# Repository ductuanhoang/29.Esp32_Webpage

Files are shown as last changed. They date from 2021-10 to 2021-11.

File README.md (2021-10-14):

# Smart hammer

This project will read data as : accelerometer and buttons and push add to AWS
* build in ESP32-IDF

#How to config wifi connect to your AP  
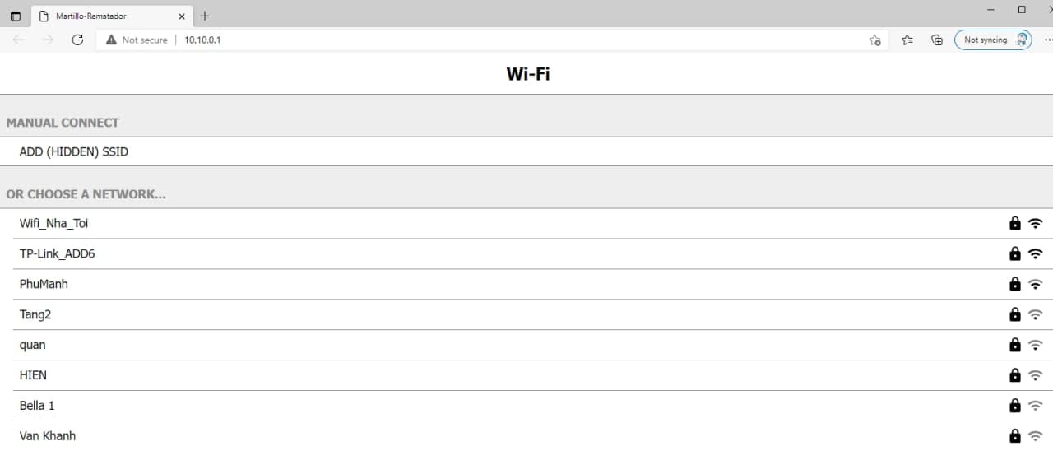
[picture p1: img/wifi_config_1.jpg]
  
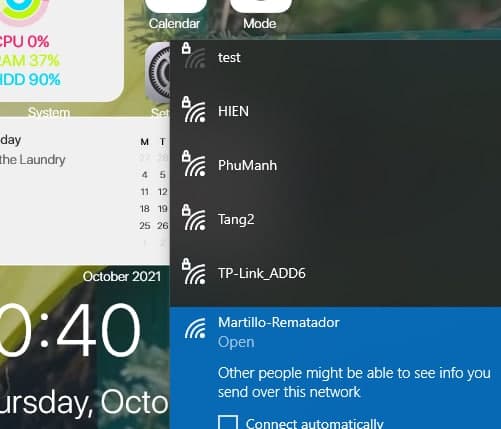
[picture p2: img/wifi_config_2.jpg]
  
#How to detect hit using Z axis  
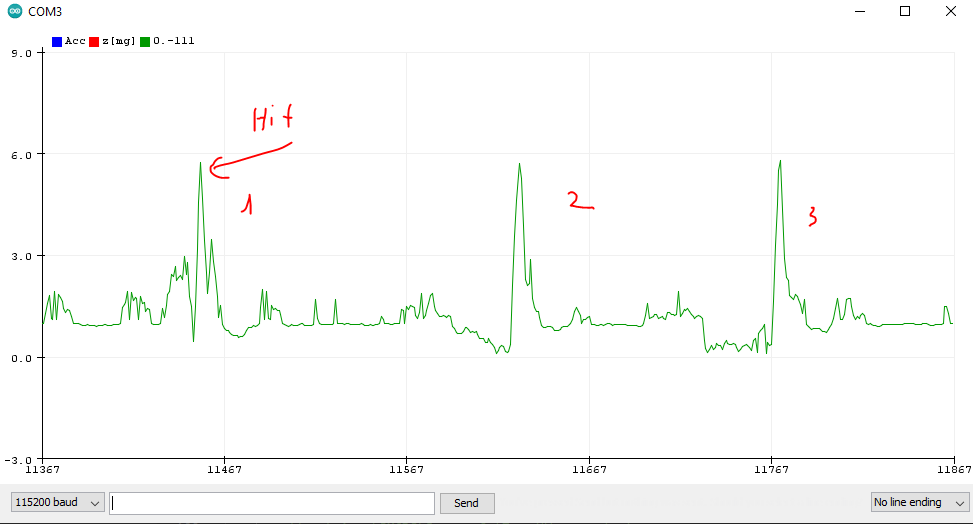
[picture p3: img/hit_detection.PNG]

#How to download the code to the esp32  
user can use "flash_download_tool" for download bin file to the esp32  
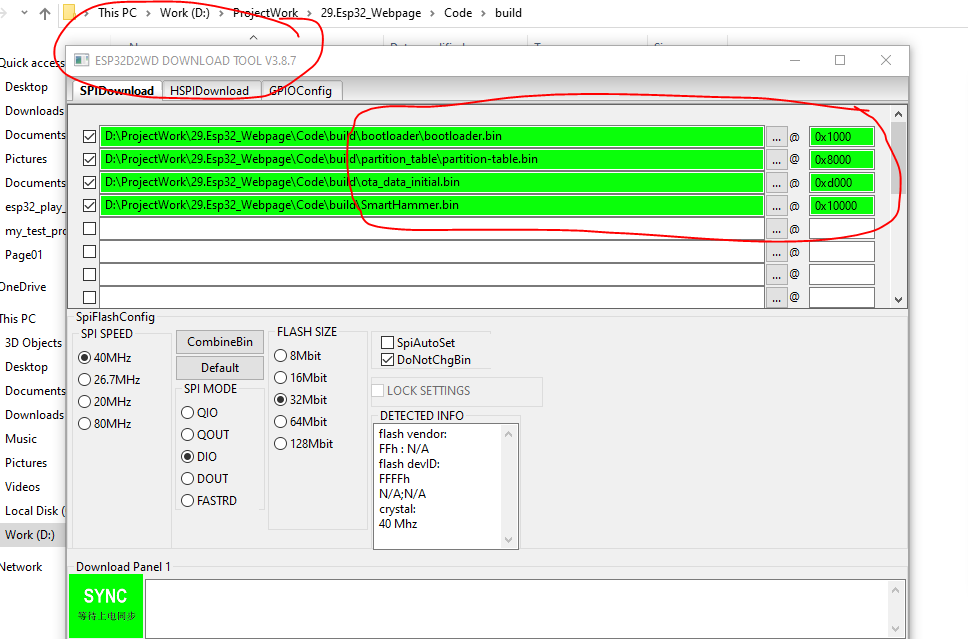
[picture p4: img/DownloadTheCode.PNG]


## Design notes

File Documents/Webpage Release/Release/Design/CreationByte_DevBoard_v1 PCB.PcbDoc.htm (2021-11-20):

Reporting Options

# File in Newer Format

Date | : | 10/28/2021
Time | : | 8:25:45 AM
Filename | : | D:\ProjectWork\29.Esp32_Webpage\Documents\Webpage Release\Release\Design\CreationByte_DevBoard_v1 PCB.PcbDoc

Version | Warning
Release 20.0 | CAUTION - Support of propagation delay for primitives

This file was generated by a later version of the software

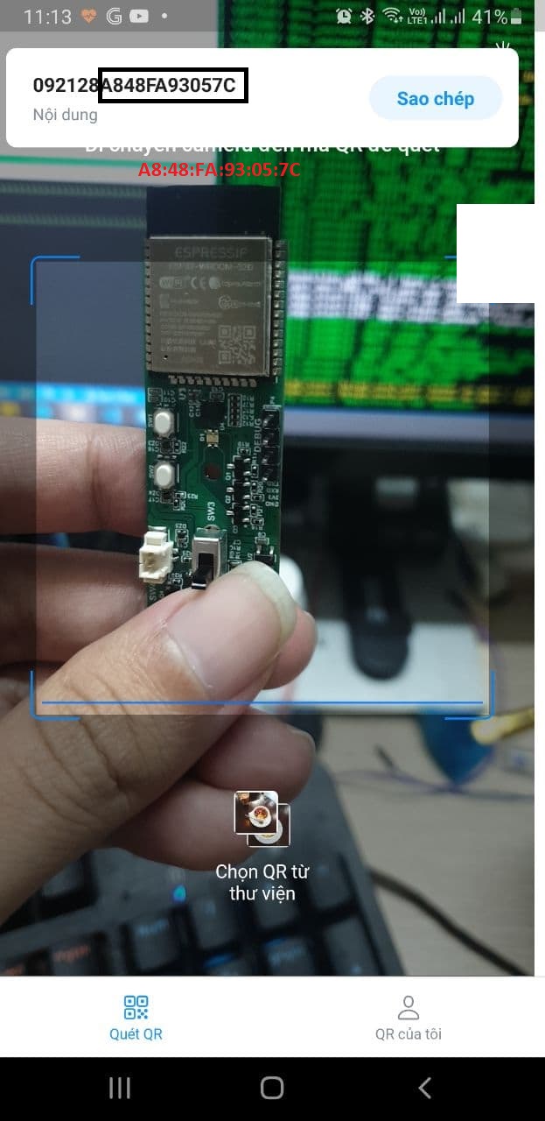
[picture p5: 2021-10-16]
img/QR_MAC_Adress.jpg

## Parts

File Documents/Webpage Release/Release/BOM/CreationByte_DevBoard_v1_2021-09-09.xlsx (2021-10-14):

Comment | Manufacturer 1 | Manufacturer Part Number 1 | Description | Designator | Quantity | SMT Quantity | Extended Price
1N4148WS | ON Semiconductor / Fairchild | 1N4148WS | DIODE GEN PURP 75V 150MA SOD323F | D2, D3 | 2 | 10 | 1.92
19-237D/BHR6GHC-C01/2T | Everlight | 19-237D/BHR6GHC-C01/2T | LED RGB CLEAR 4SMD | D1 | 1 | 5 | 1.75
BC817-25-7-F | Diodes | BC817-25-7-F | TRANS NPN 45V 500MA SOT23-3 | Q1, Q2, Q3, Q4 | 4 | 20 | 3.6
BQ24074RGTR | Texas Instruments | BQ24074RGTR | IC BATT CHG LI-ION 1CELL 16QFN | U1 | 1 | 5 | 11.5
10uF | Samsung | CL05A106MP8NUB8 | CAP CER 10UF 10V X5R 0402 | C1, C2, C3, C4, C5, C6, C8, C9, C10, C12, C15 | 11 | 55 | 9.92
0.01uF | Samsung | CL05B103KA5NNNC | CAP CER 10000PF 25V X7R 0402 | C7 | 1 | 5 | 0.5
ESP32-WROOM-32D (16MB) | Espressif Systems | ESP32-WROOM-32D (16MB) | RX TXRX MOD WIFI TRACE ANT SMD | U3 | 1 | 5 | 23.25
0.1uF | Murata | GRM155R71H104KE14D | CAP CER 0.1UF 50V X7R 0402 | C11, C13, C14, C16, C17, C18, C19 | 7 | 35 | 1.19
LCM0834A1195F | LEADER | LCM0834A1195F | Coin Type Vibration Motor | P6 | 1 | 5 | 1.64
LP502060 | Shenzhen Everwin Tech | LP502060 | LITHIUM POLYMER BATTERY 510mAh 60mm x 20mm x 5mm | P2 | 1 | 10 | 20
LSM6DSL | STMicroelectronics | LSM6DSLTR | IMU ACCEL/GYRO I2C/SPI 14LGA | U4 | 1 | 5 | 26.35
OS102011MS2QN1 | ITT C&K | OS102011MS2QN1 | Slide | SW3 | 1 | 5 | 2.55
PTS636 SP50 SMTR LFS | ITT C&K | PTS636SP50SMTRLFS | PTS636 Series SPST-NO Off-Mom 320 gf Top Actuated Gull Wing SMT Tactile Switch | SW4 | 1 | 5 | 0.6
PTS810SJK250SMTRLFS | ITT C&K | PTS810SJK250SMTRLFS | SWITCH TACTILE SPST-NO 0.05A 16V | SW1, SW2 | 2 | 10 | 3.13
1k | Yageo | RC0402FR-071KL | RES SMD 1K OHM 1% 1/16W 0402 | R1, R2, R11, R14, R16, R17, R18 | 7 | 35 | 0.56
10k | Yageo | RC0402FR-0710KL | RES SMD 10K OHM 1% 1/16W 0402 | R3, R4, R5, R6, R7, R8, R12, R13, R15, R22, R23, R25 | 12 | 60 | 0.96
33R | Yageo | RC0402FR-0733RL | RES SMD 33 OHM 1% 1/16W 0402 | R26 | 1 | 5 | 0.5
100R | Yageo | RC0402FR-07100RL | RES SMD 100 OHM 1% 1/16W 0402 | R19, R20, R21 | 3 | 15 | 0.24
100k | Yageo | RC0402JR-07100KL | RES SMD 100K OHM 1% 1/16W 0402 | R9, R10, R24 | 3 | 15 | 0.2
TPD1E10B06DPYR | Texas Instruments | TPD1E10B06DPYR | TVS DIODE 5.5V 14V 2X1SON | DZ1, DZ2, DZ3, DZ4, DZ5 | 5 | 25 | 7.43
TYPE-C-31-M-17 | Korean Hroparts Elec | TYPE-C-31-M-17 | USB - Type C Female 6 USB Connectors RoHS | USB1 | 1 | 5 | 6.4
XC6220B331MR-G | Torex | XC6220B331MR-G | IC REG LINEAR 3.3V 1A SOT25 | U2 | 1 | 5 | 4.8
PCB |  |  | PCB 2 LAYERS HASL WITH LEAD 63x20x1mm |  | 1 | 5 | 60
SMT |  |  | SMT FOR BOARD |  | 1 | 5 | 80
SMT Stencil and Setup Cost |  |  |  |  |  |  | 50
Shipping cost for total BoM |  |  |  |  |  |  | 30
Shipping cost for battery |  |  |  |  |  |  | 45
Tax fee (USD) |  |  |  |  |  |  | 59.0985
Total Price (USD) |  |  |  |  |  |  | 453.0885
Please send the payment to my PAYPAL then I can work with suppliers and factories to build prototype
My paypal accout: | manhnv.etk56@gmail.com

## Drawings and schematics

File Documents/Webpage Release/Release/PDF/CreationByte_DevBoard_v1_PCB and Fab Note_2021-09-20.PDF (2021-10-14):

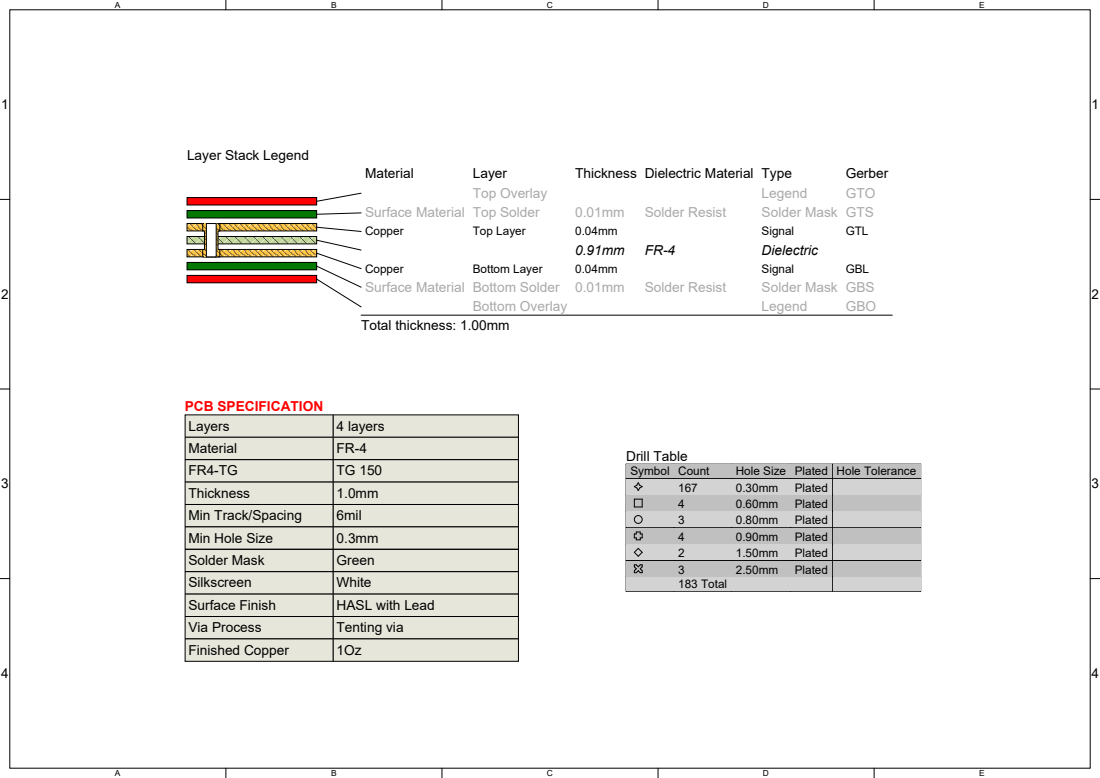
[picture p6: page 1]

Layers | 4 layers
Material | FR-4
FR4-TG | TG 150
Thickness | 1.0mm
Min Track/Spacing | 6mil

Symbol | Count | Hole Size | Plated | Hole Tolerance

167 | 0.30mm | Plated
4 | 0.60mm | Plated
3 | 0.80mm | Plated

2 | 1.50mm | Plated
3 | 2.50mm | Plated
183 Total

Solder Mask | Green
Silkscreen | White
Surface Finish | HASL with Lead
Via Process | Tenting via
Finished Copper | 1Oz

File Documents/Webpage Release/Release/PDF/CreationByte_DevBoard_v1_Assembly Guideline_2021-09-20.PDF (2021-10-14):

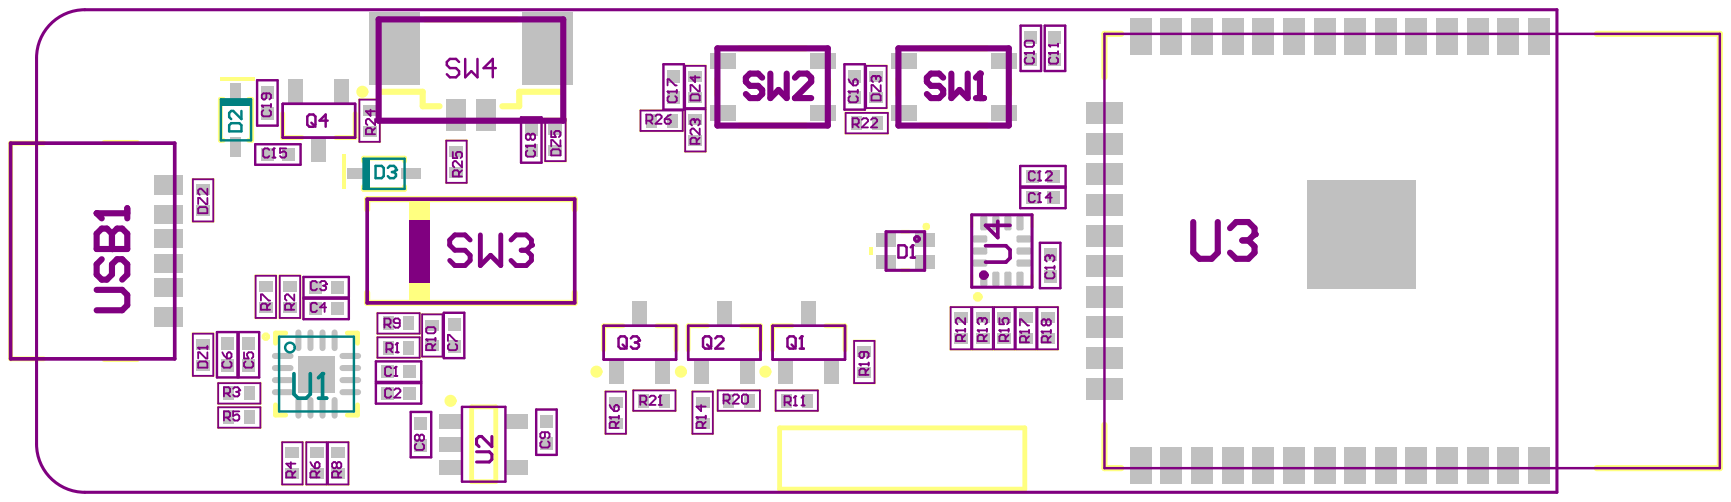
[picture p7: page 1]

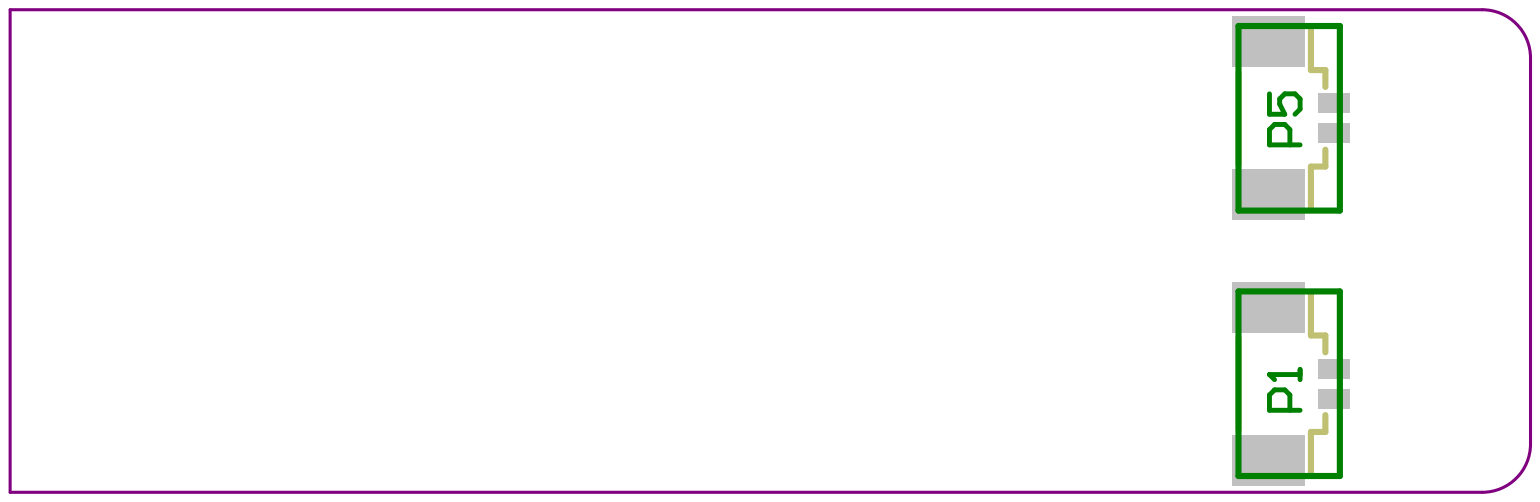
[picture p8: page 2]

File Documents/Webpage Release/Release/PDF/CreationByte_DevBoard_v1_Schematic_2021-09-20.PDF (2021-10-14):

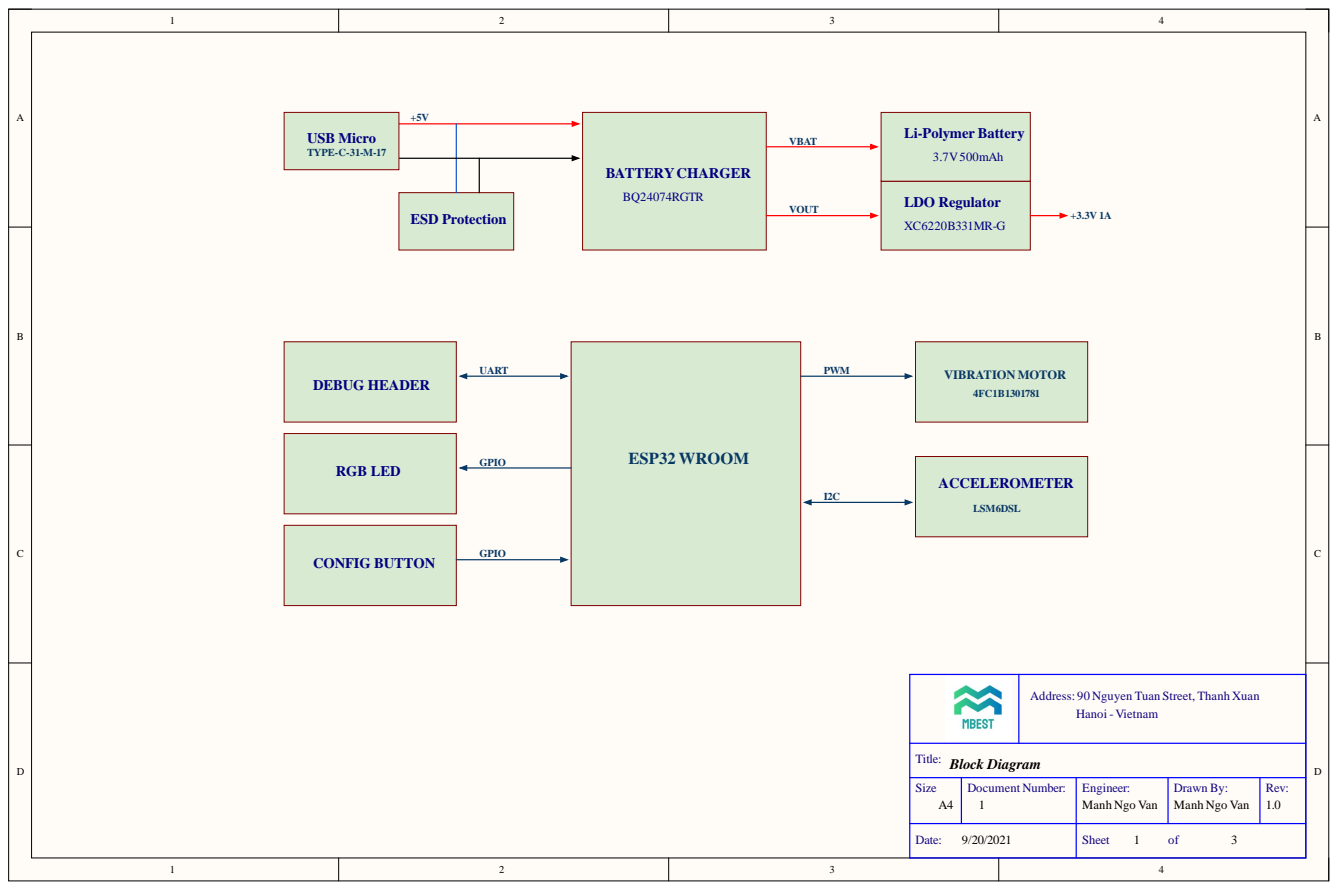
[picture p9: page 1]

Address: 90 Nguyen Tuan Street, Thanh Xuan

Size A4 | Document Number: 1 | Engineer: Manh Ngo Van | Drawn By: Manh Ngo Van | Rev: 1.0

Date: 9/20/2021 | | Sheet 1 of 3

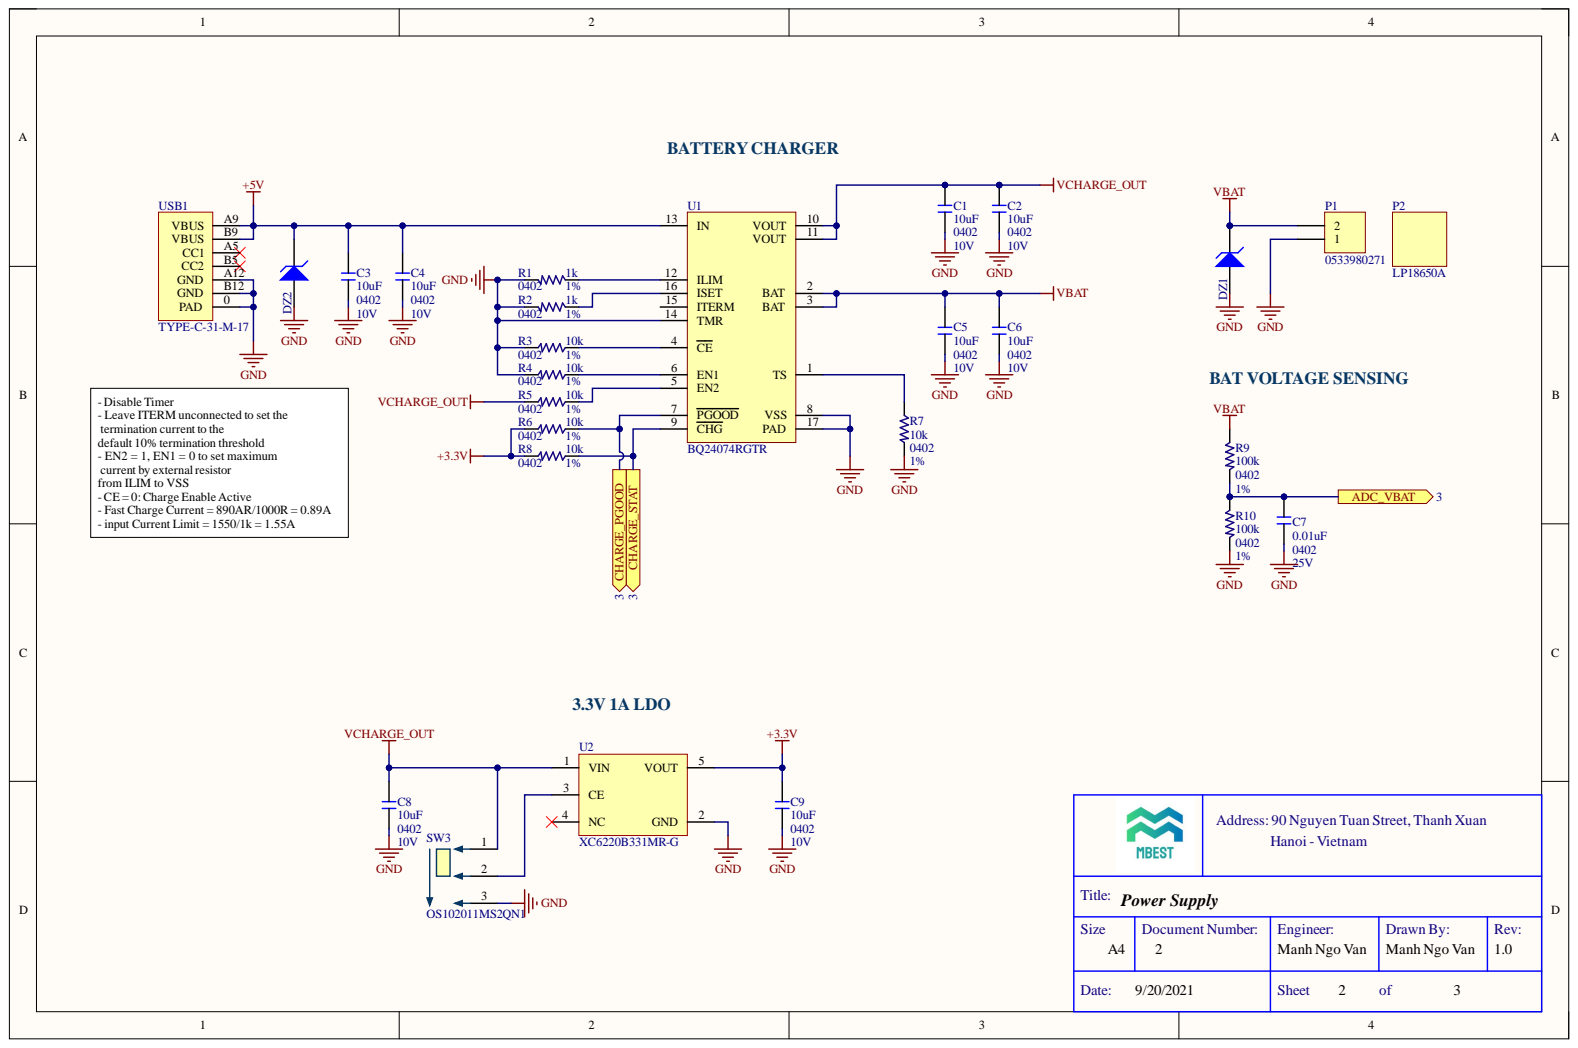
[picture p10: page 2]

cted to set the

Power Supply 9/20/2021 Si z e A4 | D ocumen t N umb e r : 2 | En g i n e e r : Man h N g o Van | D raw n B y : Man h N g o Van | R e v : 1 . 0

Dat e : | | Sh e e t 2 o f 3

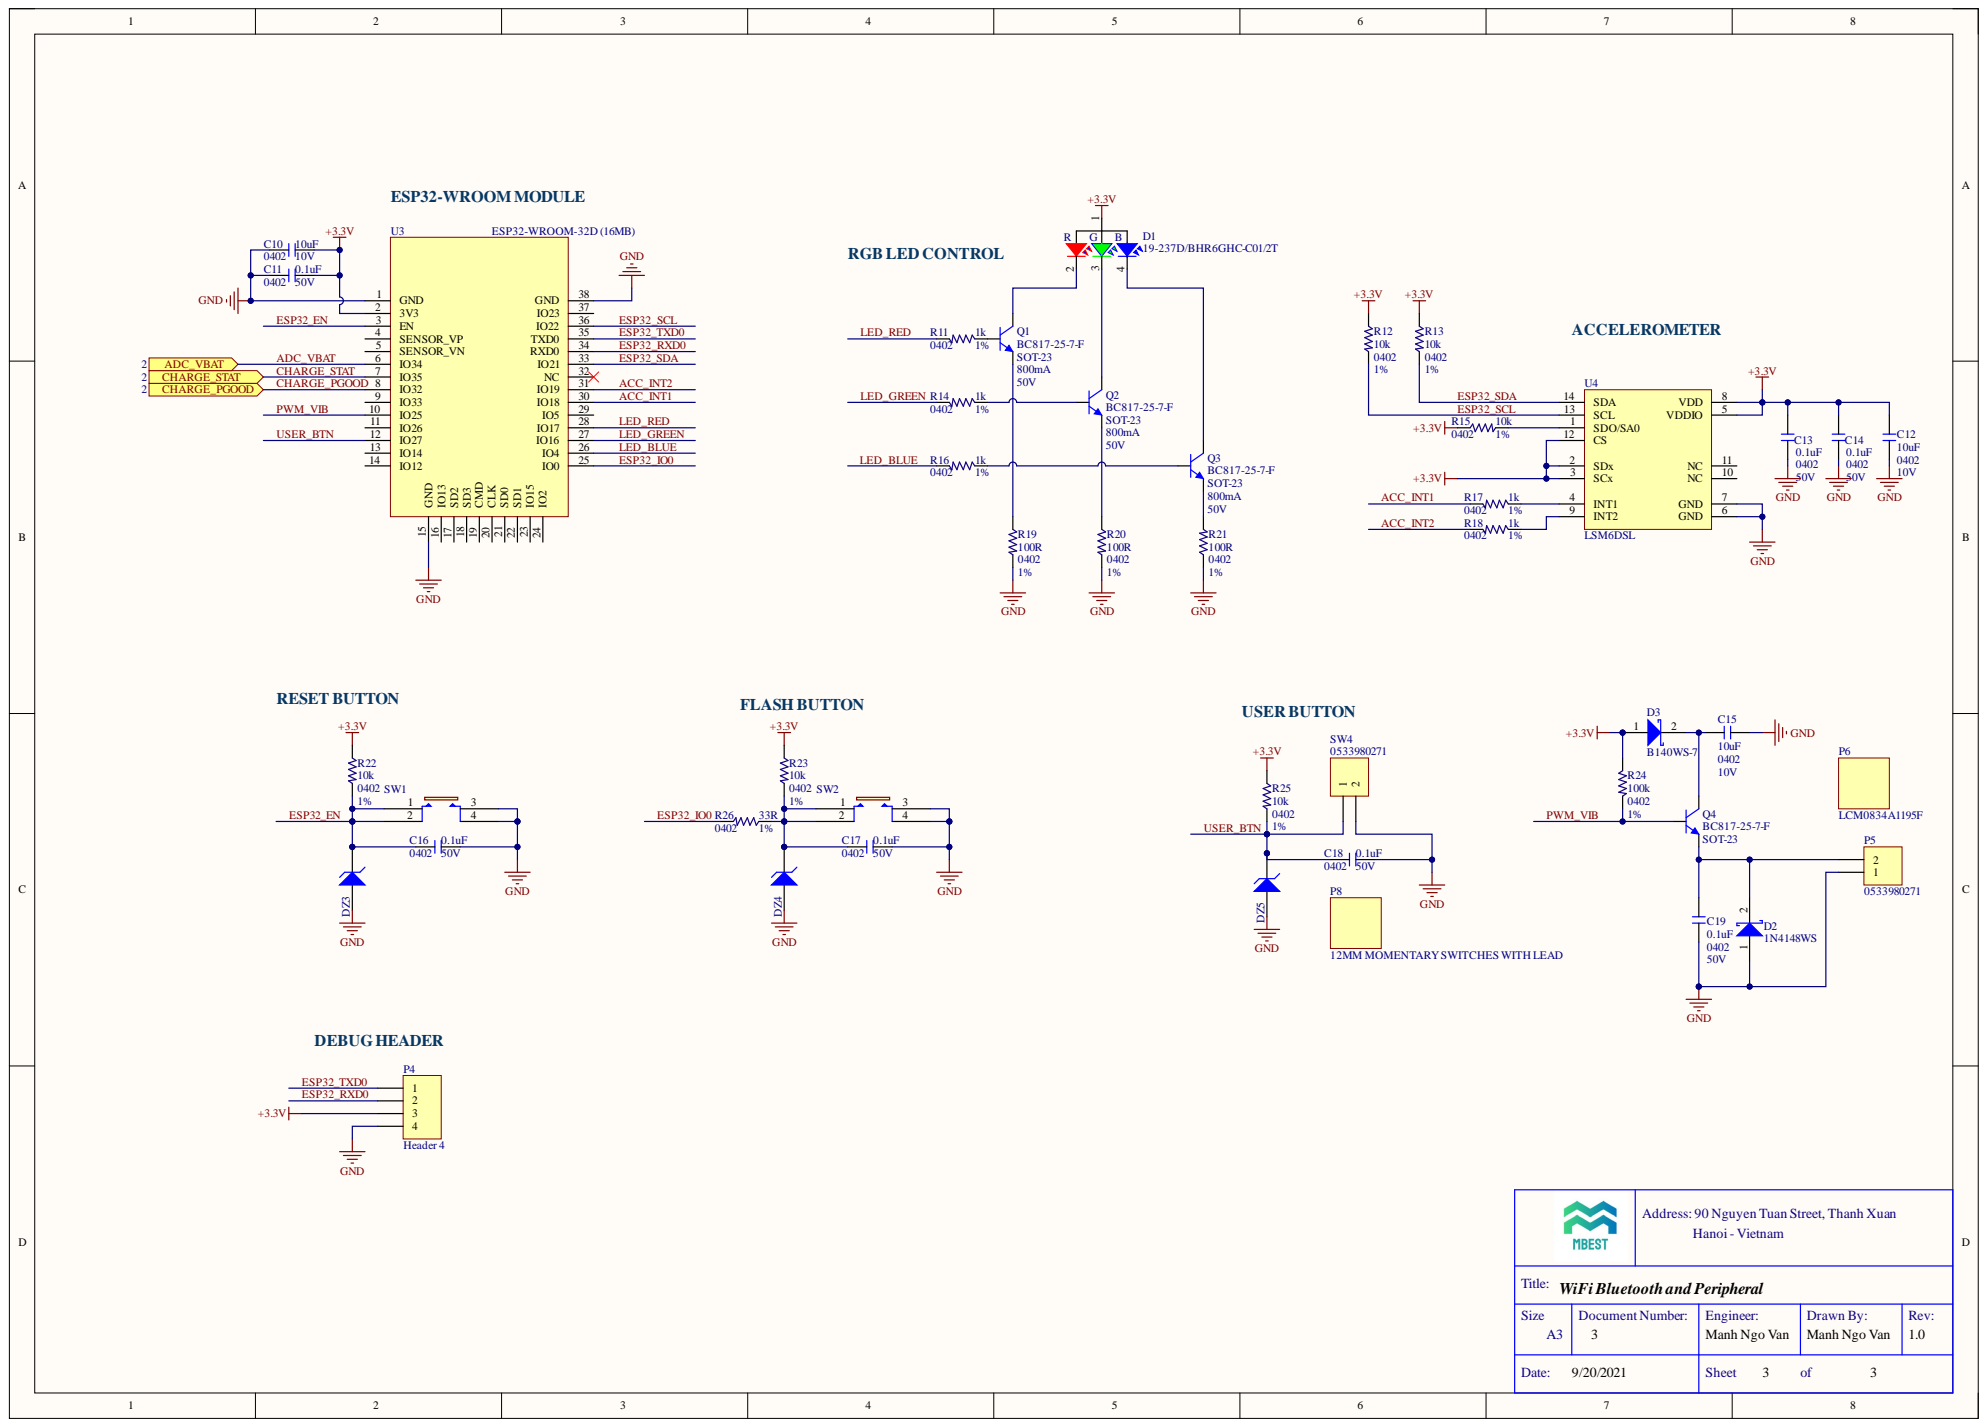
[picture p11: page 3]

Address: 90 Nguyen Tuan Street, Thanh Xuan

Size A3 | Document Number: 3 | Engineer: Manh Ngo Van | Drawn By: Manh Ngo Van | Rev: 1.0

Date: 9/20/2021 | | Sheet 3 of 3

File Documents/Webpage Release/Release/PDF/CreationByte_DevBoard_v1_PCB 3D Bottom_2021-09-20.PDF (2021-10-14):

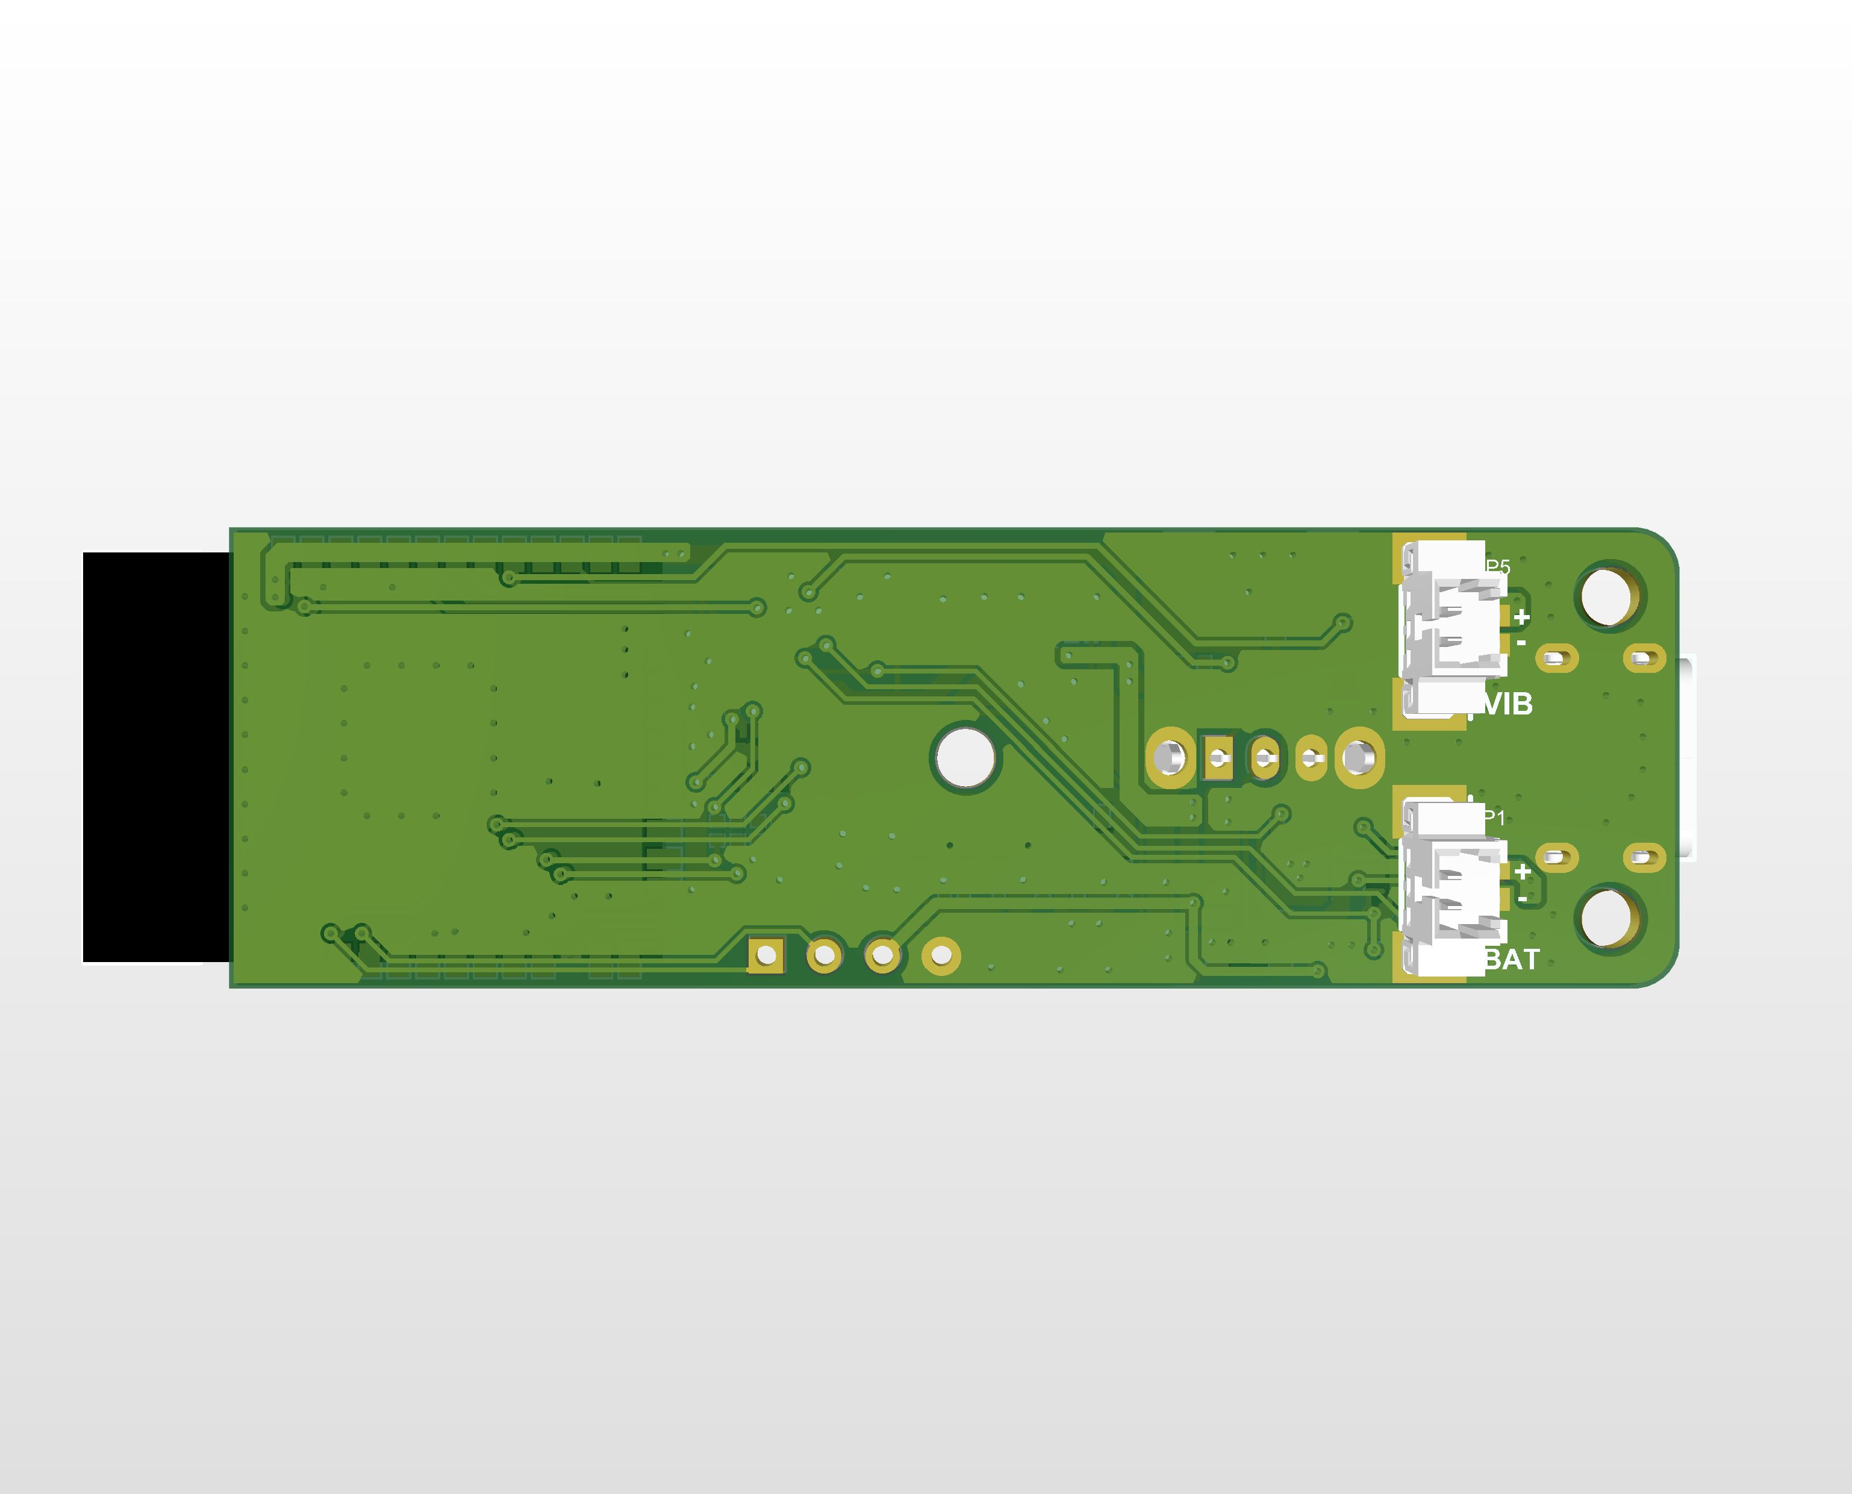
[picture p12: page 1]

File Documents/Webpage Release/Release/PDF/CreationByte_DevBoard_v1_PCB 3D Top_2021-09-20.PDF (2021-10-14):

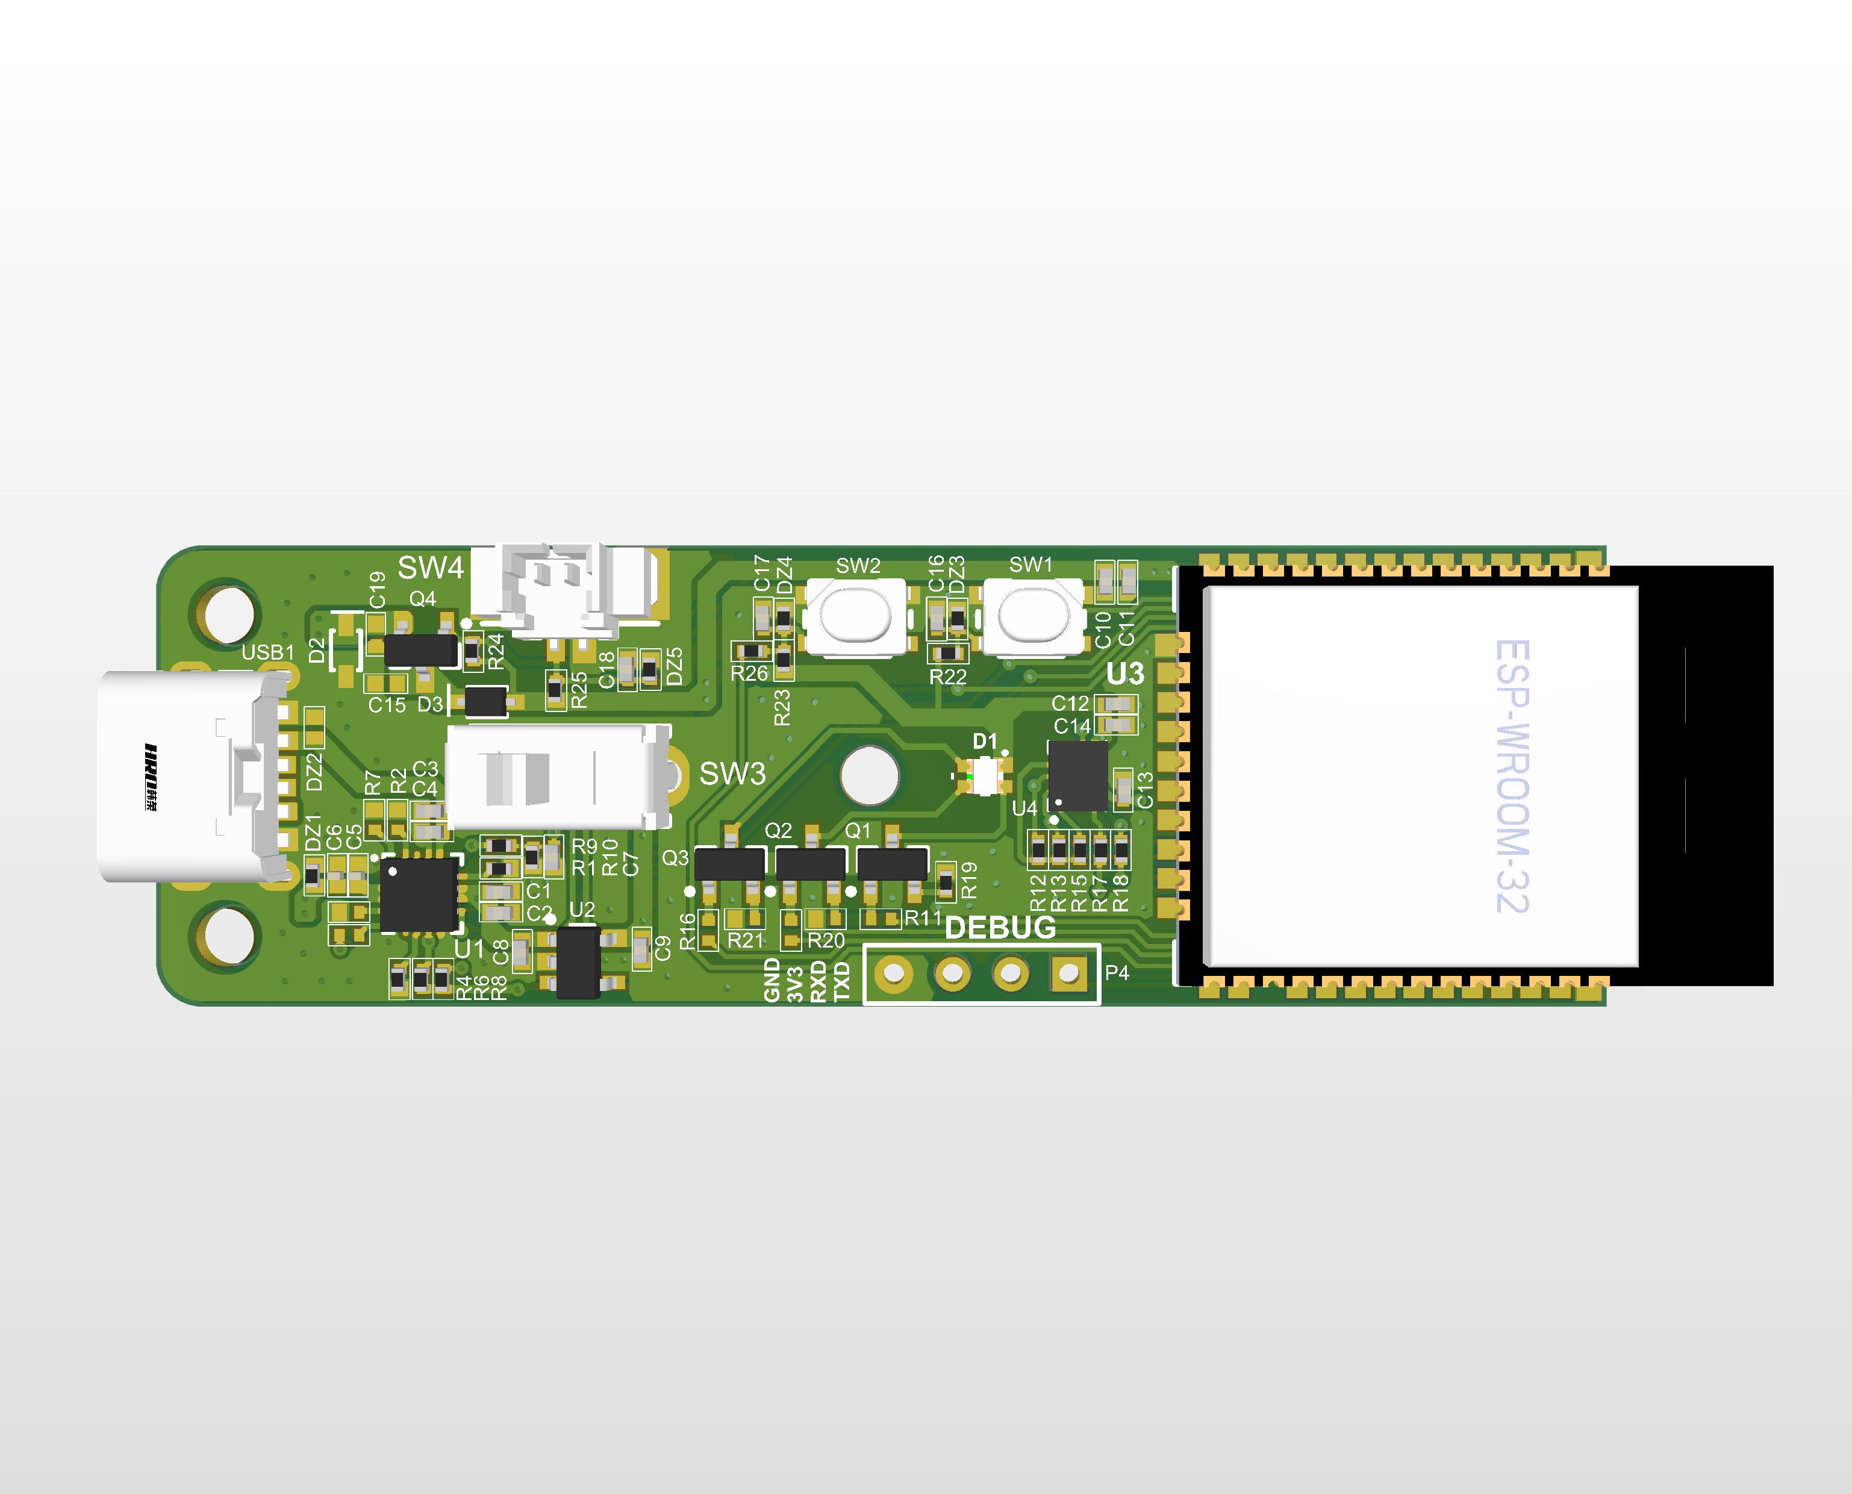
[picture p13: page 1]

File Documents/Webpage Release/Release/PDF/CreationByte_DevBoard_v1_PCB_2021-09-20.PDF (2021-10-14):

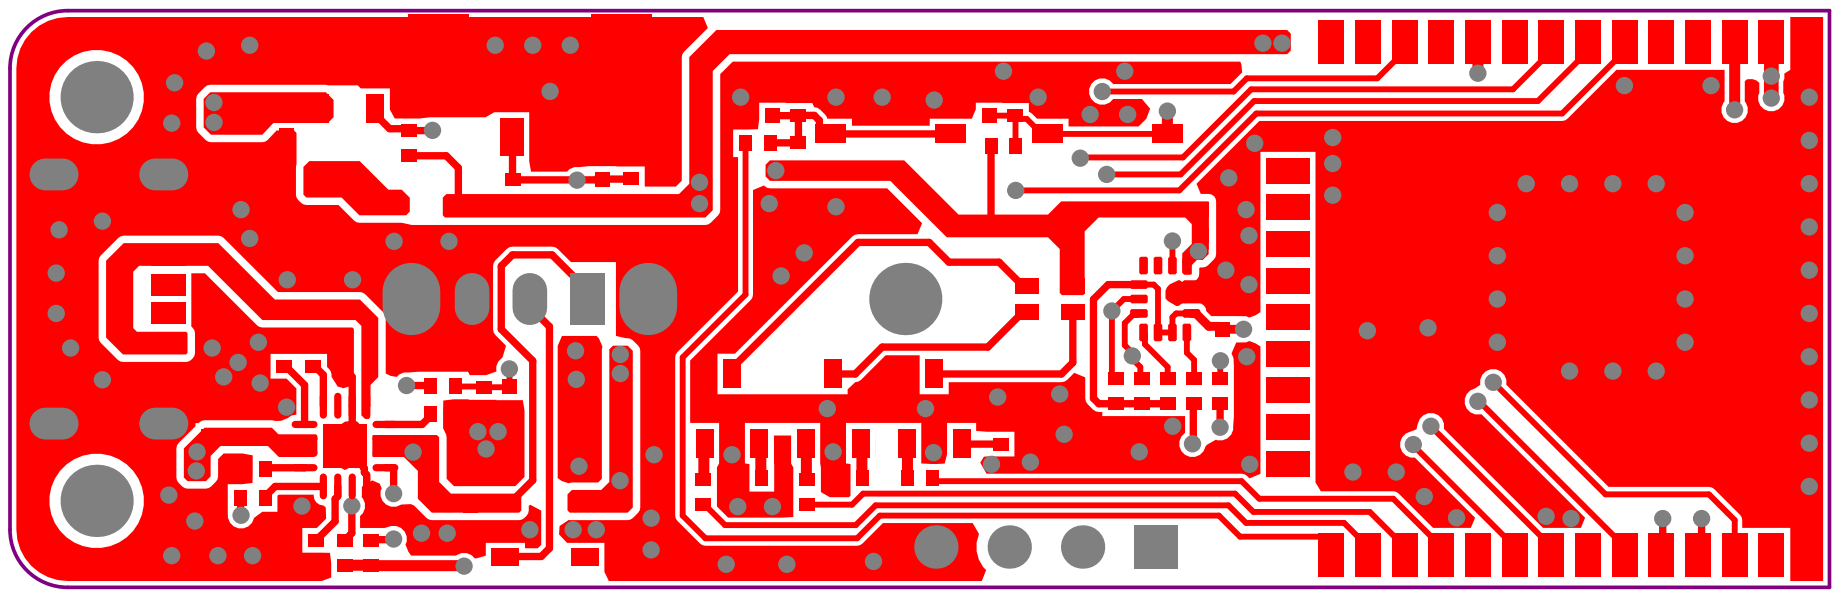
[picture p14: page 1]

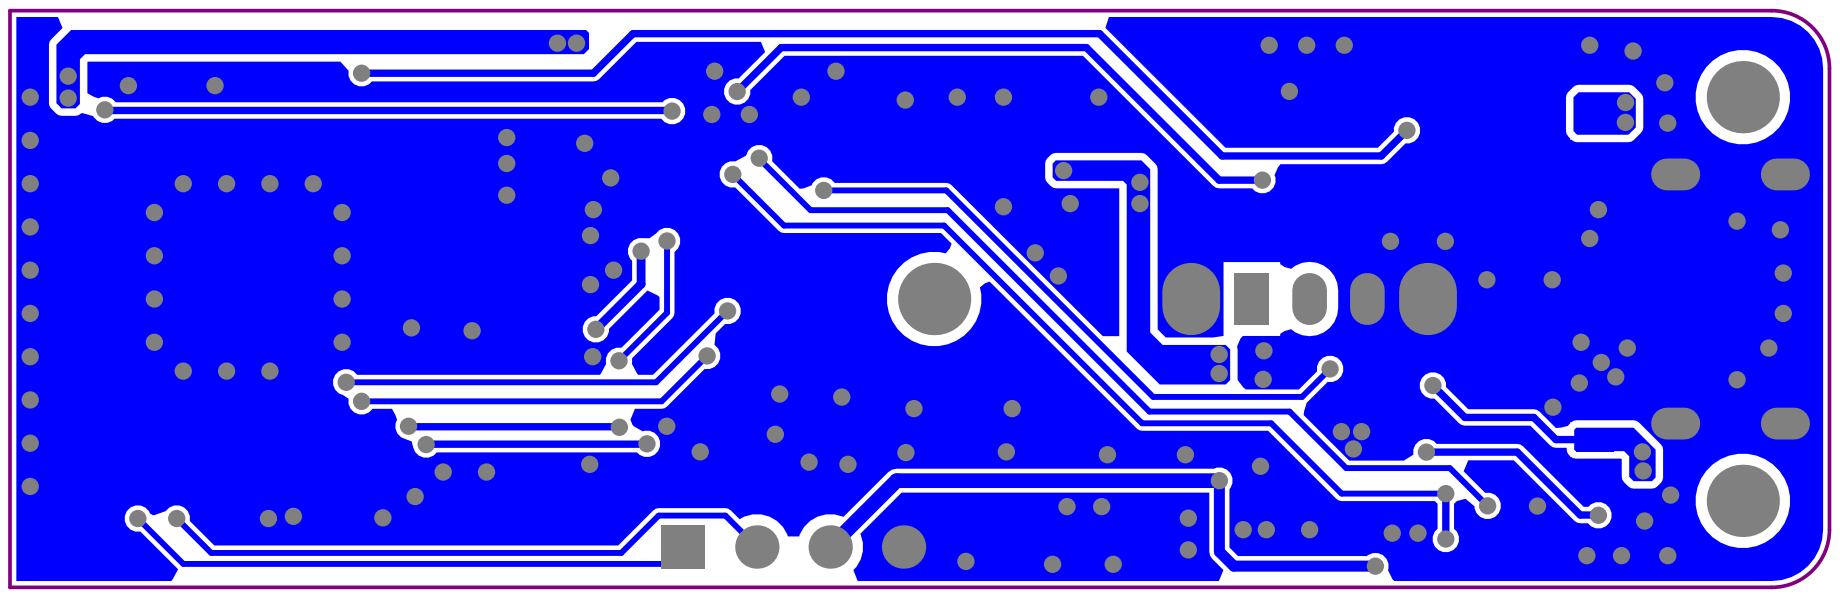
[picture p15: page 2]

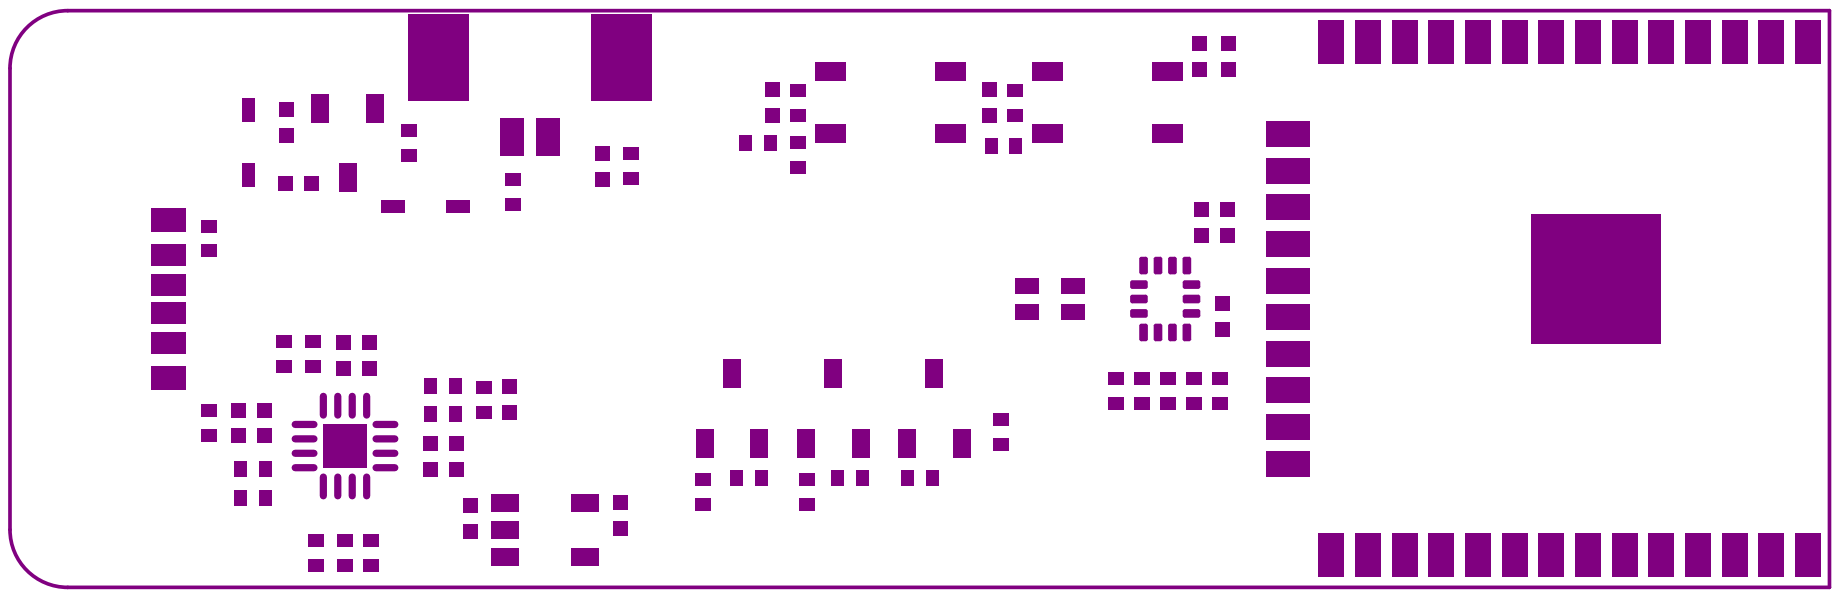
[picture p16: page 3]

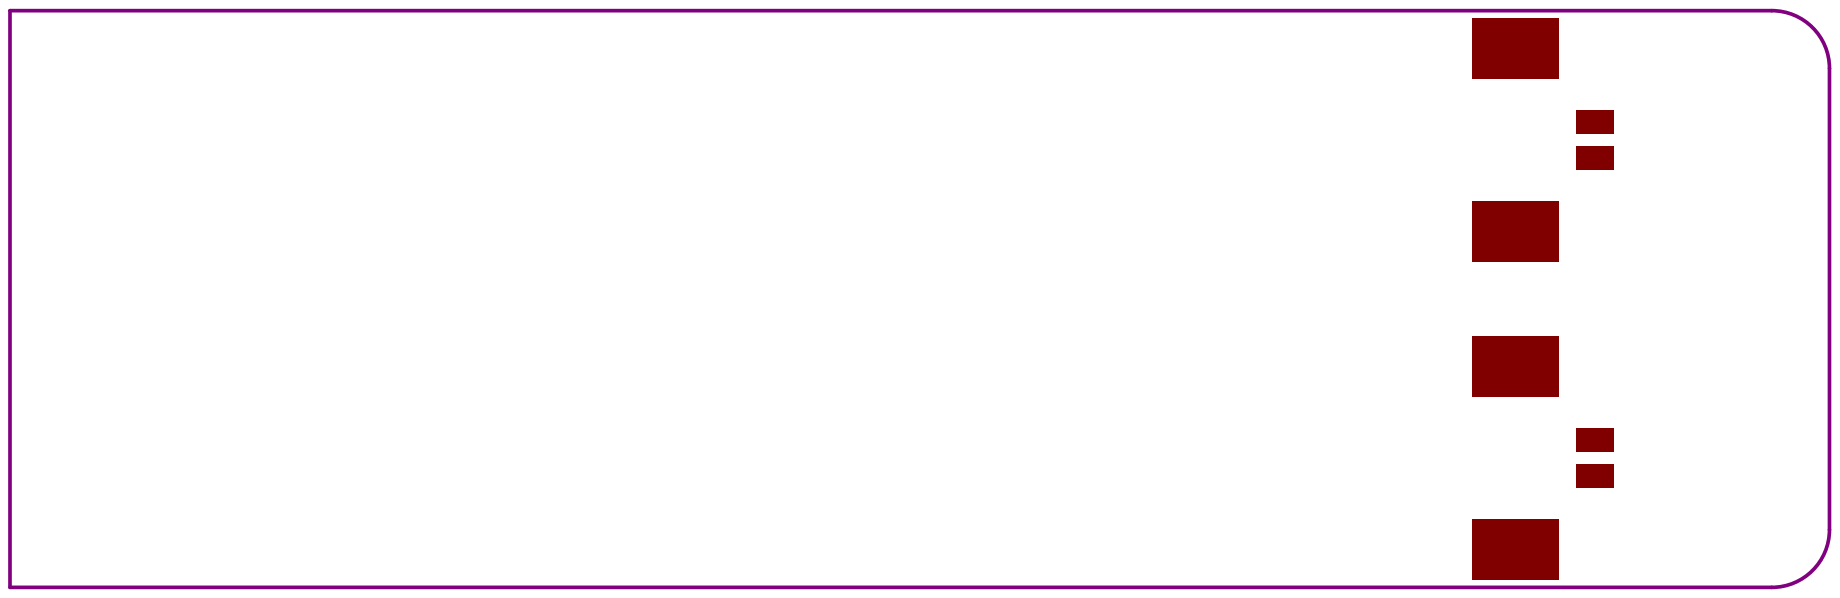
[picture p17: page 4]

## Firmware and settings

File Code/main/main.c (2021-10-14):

/* Blink Example

   This example code is in the Public Domain (or CC0 licensed, at your option.)

   Unless required by applicable law or agreed to in writing, this
   software is distributed on an "AS IS" BASIS, WITHOUT WARRANTIES OR
   CONDITIONS OF ANY KIND, either express or implied.
*/
#include <string.h>
#include "freertos/FreeRTOS.h"
#include "freertos/task.h"
#include "esp_system.h"
#include "esp_wifi.h"
#include "esp_event.h"
#include "esp_log.h"
#include "nvs_flash.h"

#include "lwip/err.h"
#include "lwip/sys.h"

#include "esp_spiffs.h"

#include "../Common.h"
#include "../task/mqtt_task.h"
#include "../task/plan_task.h"
#include "../task/imu_read_task.h"

#include "../components/json_parser/json_parser.h"
#include "../components/esp32_wifi_manager/src/wifi_manager.h"
#include "../components/peripheral/user_timer.h"

#include "../user_driver/user_buttons.h"
#include "../user_driver/user_leds.h"
#include "../user_driver/user_vibration_motor.h"
#include "../user_driver/LSM6DSL_ACC_GYRO_Driver.h"
/* Can use project configuration menu (idf.py menuconfig) to choose the GPIO to blink,
   or you can edit the following line and set a number here.
*/
deive_data_t deive_data;
mqtt_config_t mqtt_config;

esp_vfs_spiffs_conf_t conf = {
    .base_path = "/spiffs",
    .partition_label = NULL,
    .max_files = 5,
    .format_if_mount_failed = true};

void flash_file_init(void)
{
    esp_err_t ret = esp_vfs_spiffs_register(&conf);

    if (ret != ESP_OK)
    {
        if (ret == ESP_FAIL)
        {
            APP_LOGE("Failed to mount or format filesystem");
        }
        else if (ret == ESP_ERR_NOT_FOUND)
        {
            APP_LOGE("Failed to find SPIFFS partition");
        }
        else
        {
            APP_LOGE("Failed to initialize SPIFFS (%d)", ret);
        }
    }
}

void flash_erase_all_partions(void)
{
    APP_LOGI("erase all nvs partions");
    nvs_flash_erase();
    APP_LOGI("erase all spiffs partions");
    esp_spiffs_format(conf.partition_label);
    esp_vfs_spiffs_unregister(&conf);
}

void cb_connection_ok(void *pvParameter)
{
    ip_event_got_ip_t *param = (ip_event_got_ip_t *)pvParameter;

    /* transform IP to human readable string */
    char str_ip[16];
    esp_ip4addr_ntoa(&param->ip_info.ip, str_ip, IP4ADDR_STRLEN_MAX);

    APP_LOGI("I have a connection and my IP is %s!", str_ip);
    deive_data.wifi_status = true;
    mqtt_task_start();
}

void app_main(void)
{
    APP_LOGI("--- APP_MAIN: Smart Hammer Update 14/10/2021......");
    APP_LOGI("--- APP_MAIN: Free memory: %d bytes", esp_get_free_heap_size());
    //Initialize NVS
    esp_err_t ret = nvs_flash_init();
    if (ret == ESP_ERR_NVS_NO_FREE_PAGES || ret == ESP_ERR_NVS_NEW_VERSION_FOUND)
    {
        ESP_ERROR_CHECK(nvs_flash_erase());
        ret = nvs_flash_init();
    }
    flash_file_init();
    ESP_ERROR_CHECK(ret);
    //Initialize values
    deive_data.sensor.vibration_level = 50; //setting values vibration_level is 50 percent
    deive_data.sensor.hammer_detect = 0;
    deive_data.sensor.vibration_active = false;
    // load save param
    UserTimer_Init();

    buttons_gpio_init();
    leds_gpio_init();
    vibration_init();
    /* start the wifi manager */
    wifi_manager_start();
    /* register a callback as an example to how you can integrate your code with the wifi manager */
    wifi_manager_set_callback(WM_EVENT_STA_GOT_IP, &cb_connection_ok);

    plan_task();
    imu_read_task();
}

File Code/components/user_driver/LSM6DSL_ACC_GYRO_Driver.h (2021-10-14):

/**
 ******************************************************************************
 * @file    LSM6DSL_ACC_GYRO_driver.h
 * @author  MEMS Application Team
 * @version V1.5
 * @date    17-May-2016
 * @brief   LSM6DSL header driver file
 ******************************************************************************
 * @attention
 *
 * <h2><center>&copy; COPYRIGHT(c) 2017 STMicroelectronics</center></h2>
 *
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
 ******************************************************************************
 */

/* Define to prevent recursive inclusion -------------------------------------*/
#ifndef __LSM6DSL_ACC_GYRO_DRIVER__H
#define __LSM6DSL_ACC_GYRO_DRIVER__H

/* Includes ------------------------------------------------------------------*/
#include <stdint.h>
/* Exported types ------------------------------------------------------------*/

#ifdef __cplusplus
extern "C" {
#endif

//these could change accordingly with the architecture

#ifndef __ARCHDEP__TYPES
#define __ARCHDEP__TYPES

typedef unsigned char u8_t;
typedef unsigned short int u16_t;
typedef unsigned int u32_t;
typedef int i32_t;
typedef short int i16_t;
typedef signed char i8_t;

#endif /*__ARCHDEP__TYPES*/

/* Exported common structure --------------------------------------------------------*/

#ifndef __SHARED__TYPES
#define __SHARED__TYPES

typedef union{
	i16_t i16bit[3];
	u8_t u8bit[6];
} Type3Axis16bit_U;

typedef union{
	i16_t i16bit;
	u8_t u8bit[2];
} Type1Axis16bit_U;

typedef union{
	i32_t i32bit;
	u8_t u8bit[4];
} Type1Axis32bit_U;

typedef enum {
  MEMS_SUCCESS				=		0x01,
  MEMS_ERROR				=		0x00
} mems_status_t;

#endif /*__SHARED__TYPES*/

/* Exported macro ------------------------------------------------------------*/

/* Exported constants --------------------------------------------------------*/

/************** I2C Address *****************/

// #define LSM6DSL_ACC_GYRO_I2C_ADDRESS_LOW   0xD4  // SAD[0] = 0
// #define LSM6DSL_ACC_GYRO_I2C_ADDRESS_HIGH  0xD6  // SAD[0] = 1

/************** I2C Address *****************/

#define LSM6DSL_ACC_GYRO_I2C_ADDRESS_LOW 0x6A  // SAD[0] = 0
#define LSM6DSL_ACC_GYRO_I2C_ADDRESS_HIGH 0x6B // SAD[0] = 1

/************** Who am I  *******************/

#define LSM6DSL_ACC_GYRO_WHO_AM_I         0x6A

/************** Device Register  *******************/

#define LSM6DSL_ACC_GYRO_FUNC_CFG_ACCESS  	0X01

#define LSM6DSL_ACC_GYRO_SENSOR_SYNC_TIME  	0X04
#define LSM6DSL_ACC_GYRO_SENSOR_RES_RATIO  	0X05

#define LSM6DSL_ACC_GYRO_FIFO_CTRL1  	0X06
#define LSM6DSL_ACC_GYRO_FIFO_CTRL2  	0X07
#define LSM6DSL_ACC_GYRO_FIFO_CTRL3  	0X08
#define LSM6DSL_ACC_GYRO_FIFO_CTRL4  	0X09
#define LSM6DSL_ACC_GYRO_FIFO_CTRL5  	0X0A

#define LSM6DSL_ACC_GYRO_DRDY_PULSE_CFG_G  	0X0B
#define LSM6DSL_ACC_GYRO_INT1_CTRL  	0X0D
#define LSM6DSL_ACC_GYRO_INT2_CTRL  	0X0E
#define LSM6DSL_ACC_GYRO_WHO_AM_I_REG  	0X0F
#define LSM6DSL_ACC_GYRO_CTRL1_XL  	0X10
#define LSM6DSL_ACC_GYRO_CTRL2_G  	0X11
#define LSM6DSL_ACC_GYRO_CTRL3_C  	0X12
#define LSM6DSL_ACC_GYRO_CTRL4_C  	0X13
#define LSM6DSL_ACC_GYRO_CTRL5_C  	0X14
#define LSM6DSL_ACC_GYRO_CTRL6_G  	0X15
#define LSM6DSL_ACC_GYRO_CTRL7_G  	0X16
#define LSM6DSL_ACC_GYRO_CTRL8_XL  	0X17
#define LSM6DSL_ACC_GYRO_CTRL9_XL  	0X18
#define LSM6DSL_ACC_GYRO_CTRL10_C  	0X19

#define LSM6DSL_ACC_GYRO_MASTER_CONFIG  	0X1A
#define LSM6DSL_ACC_GYRO_WAKE_UP_SRC  	0X1B
#define LSM6DSL_ACC_GYRO_TAP_SRC  	0X1C
#define LSM6DSL_ACC_GYRO_D6D_SRC  	0X1D
#define LSM6DSL_ACC_GYRO_STATUS_REG  	0X1E

#define LSM6DSL_ACC_GYRO_OUT_TEMP_L  	0X20
#define LSM6DSL_ACC_GYRO_OUT_TEMP_H  	0X21
#define LSM6DSL_ACC_GYRO_OUTX_L_G  	0X22
#define LSM6DSL_ACC_GYRO_OUTX_H_G  	0X23
#define LSM6DSL_ACC_GYRO_OUTY_L_G  	0X24
#define LSM6DSL_ACC_GYRO_OUTY_H_G  	0X25
#define LSM6DSL_ACC_GYRO_OUTZ_L_G  	0X26
#define LSM6DSL_ACC_GYRO_OUTZ_H_G  	0X27
#define LSM6DSL_ACC_GYRO_OUTX_L_XL  	0X28
#define LSM6DSL_ACC_GYRO_OUTX_H_XL  	0X29
#define LSM6DSL_ACC_GYRO_OUTY_L_XL  	0X2A
#define LSM6DSL_ACC_GYRO_OUTY_H_XL  	0X2B
#define LSM6DSL_ACC_GYRO_OUTZ_L_XL  	0X2C
#define LSM6DSL_ACC_GYRO_OUTZ_H_XL  	0X2D
#define LSM6DSL_ACC_GYRO_SENSORHUB1_REG  	0X2E
#define LSM6DSL_ACC_GYRO_SENSORHUB2_REG  	0X2F
#define LSM6DSL_ACC_GYRO_SENSORHUB3_REG  	0X30
#define LSM6DSL_ACC_GYRO_SENSORHUB4_REG  	0X31
#define LSM6DSL_ACC_GYRO_SENSORHUB5_REG  	0X32
#define LSM6DSL_ACC_GYRO_SENSORHUB6_REG  	0X33
#define LSM6DSL_ACC_GYRO_SENSORHUB7_REG  	0X34
#define LSM6DSL_ACC_GYRO_SENSORHUB8_REG  	0X35
#define LSM6DSL_ACC_GYRO_SENSORHUB9_REG  	0X36
#define LSM6DSL_ACC_GYRO_SENSORHUB10_REG  	0X37
#define LSM6DSL_ACC_GYRO_SENSORHUB11_REG  	0X38
#define LSM6DSL_ACC_GYRO_SENSORHUB12_REG  	0X39
#define LSM6DSL_ACC_GYRO_FIFO_STATUS1  	0X3A
#define LSM6DSL_ACC_GYRO_FIFO_STATUS2  	0X3B
#define LSM6DSL_ACC_GYRO_FIFO_STATUS3  	0X3C
#define LSM6DSL_ACC_GYRO_FIFO_STATUS4  	0X3D
#define LSM6DSL_ACC_GYRO_FIFO_DATA_OUT_L  	0X3E
#define LSM6DSL_ACC_GYRO_FIFO_DATA_OUT_H  	0X3F
#define LSM6DSL_ACC_GYRO_TIMESTAMP0_REG  	0X40
#define LSM6DSL_ACC_GYRO_TIMESTAMP1_REG  	0X41
#define LSM6DSL_ACC_GYRO_TIMESTAMP2_REG  	0X42

#define LSM6DSL_ACC_GYRO_TIMESTAMP_L  	0X49
#define LSM6DSL_ACC_GYRO_TIMESTAMP_H  	0X4A

#define LSM6DSL_ACC_GYRO_STEP_COUNTER_L  	0X4B
#define LSM6DSL_ACC_GYRO_STEP_COUNTER_H  	0X4C

#define LSM6DSL_ACC_GYRO_SENSORHUB13_REG  	0X4D
#define LSM6DSL_ACC_GYRO_SENSORHUB14_REG  	0X4E
#define LSM6DSL_ACC_GYRO_SENSORHUB15_REG  	0X4F
#define LSM6DSL_ACC_GYRO_SENSORHUB16_REG  	0X50
#define LSM6DSL_ACC_GYRO_SENSORHUB17_REG  	0X51
#define LSM6DSL_ACC_GYRO_SENSORHUB18_REG  	0X52

#define LSM6DSL_ACC_GYRO_FUNC_SRC  	0X53
#define LSM6DSL_ACC_GYRO_TAP_CFG1  	0X58
#define LSM6DSL_ACC_GYRO_TAP_THS_6D  	0X59
#define LSM6DSL_ACC_GYRO_INT_DUR2  	0X5A
#define LSM6DSL_ACC_GYRO_WAKE_UP_THS  	0X5B
#define LSM6DSL_ACC_GYRO_WAKE_UP_DUR  	0X5C
#define LSM6DSL_ACC_GYRO_FREE_FALL  	0X5D
#define LSM6DSL_ACC_GYRO_MD1_CFG  	0X5E
#define LSM6DSL_ACC_GYRO_MD2_CFG  	0X5F

#define LSM6DSL_ACC_GYRO_OUT_MAG_RAW_X_L  	0X66
#define LSM6DSL_ACC_GYRO_OUT_MAG_RAW_X_H  	0X67
#define LSM6DSL_ACC_GYRO_OUT_MAG_RAW_Y_L  	0X68
#define LSM6DSL_ACC_GYRO_OUT_MAG_RAW_Y_H  	0X69
#define LSM6DSL_ACC_GYRO_OUT_MAG_RAW_Z_L  	0X6A
#define LSM6DSL_ACC_GYRO_OUT_MAG_RAW_Z_H  	0X6B

#define LSM6DSL_ACC_GYRO_X_OFS_USR  	0X73
#define LSM6DSL_ACC_GYRO_Y_OFS_USR  	0X74
#define LSM6DSL_ACC_GYRO_Z_OFS_USR  	0X75
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

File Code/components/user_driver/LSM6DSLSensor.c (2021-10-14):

/**
 ******************************************************************************
 * @file    LSM6DSLSensor.cpp
 * @author  AST
 * @version V1.0.0
 * @date    7 September 2017
 * @brief   Implementation of an LSM6DSL Inertial Measurement Unit (IMU) 6 axes
 *          sensor.
 ******************************************************************************
 * @attention
 *
 * <h2><center>&copy; COPYRIGHT(c) 2017 STMicroelectronics</center></h2>
 *
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
 ******************************************************************************
 */

/* Includes ------------------------------------------------------------------*/
#include "LSM6DSLSensor.h"
#include "../peripheral/user_i2c.h"
#include "../../Common.h"
/* Private typedef -----------------------------------------------------------*/


/* Private define ------------------------------------------------------------*/
#define I2C_MASTER_NUM 0 /*!< I2C master i2c port number, the number of i2c peripheral interfaces available will depend on the chip */
#define I2C_SCL_PIN 22
#define I2C_SDA_PIN 21
#define I2C_FREQ_100K 100000

/* Private functions ---------------------------------------------------------*/
static LSM6DSLStatusTypeDef Set_X_ODR_When_Enabled(float odr);
static LSM6DSLStatusTypeDef Set_G_ODR_When_Enabled(float odr);
static LSM6DSLStatusTypeDef Set_X_ODR_When_Disabled(float odr);
static LSM6DSLStatusTypeDef Set_G_ODR_When_Disabled(float odr);

static uint8_t X_isEnabled;
static float X_Last_ODR;
static uint8_t G_isEnabled;
static float G_Last_ODR;

/**
 * @brief  Configure the sensor in order to be used
 * @retval 0 in case of success, an error code otherwise
 */
LSM6DSLStatusTypeDef LSM6DSLSensor_begin()
{
    X_isEnabled = 0;
    G_isEnabled = 0;

    int ret = i2c_master_init(I2C_MASTER_NUM, I2C_SDA_PIN, I2C_SCL_PIN, I2C_FREQ_100K);
    if (ret == ESP_OK)
        APP_LOGI("LSM6DSL_ACC_GYRO_Init = %d", ret);
    else
        APP_LOGI("LSM6DSL_ACC_GYRO_Init err");

    /* Enable register address automatically incremented during a multiple byte
     access with a serial interface. */
    if (LSM6DSL_ACC_GYRO_W_IF_Addr_Incr(NULL, LSM6DSL_ACC_GYRO_IF_INC_ENABLED) == MEMS_ERROR)
    {
        return LSM6DSL_STATUS_ERROR;
    }

    /* Enable BDU */
    if (LSM6DSL_ACC_GYRO_W_BDU(NULL, LSM6DSL_ACC_GYRO_BDU_BLOCK_UPDATE) == MEMS_ERROR)
    {
        return LSM6DSL_STATUS_ERROR;
    }

    /* FIFO mode selection */
    if (LSM6DSL_ACC_GYRO_W_FIFO_MODE(NULL, LSM6DSL_ACC_GYRO_FIFO_MODE_BYPASS) == MEMS_ERROR)
    {
        return LSM6DSL_STATUS_ERROR;
    }

    /* Output data rate selection - power down. */
    if (LSM6DSL_ACC_GYRO_W_ODR_XL(NULL, LSM6DSL_ACC_GYRO_ODR_XL_POWER_DOWN) == MEMS_ERROR)
    {
        return LSM6DSL_STATUS_ERROR;
    }

    /* Full scale selection. */
    if (LSM6DSLSensor_Set_X_FS(8.0f) == LSM6DSL_STATUS_ERROR)
    {
        return LSM6DSL_STATUS_ERROR;
    }

    /* Output data rate selection - power down */
    if (LSM6DSL_ACC_GYRO_W_ODR_G(NULL, LSM6DSL_ACC_GYRO_ODR_G_POWER_DOWN) == MEMS_ERROR)
    {
        return LSM6DSL_STATUS_ERROR;
    }

    /* Full scale selection. */
    if (LSM6DSLSensor_Set_G_FS(2000.0f) == LSM6DSL_STATUS_ERROR)
    {
        return LSM6DSL_STATUS_ERROR;
    }

    X_Last_ODR = 104.0f;

    X_isEnabled = 0;

    G_Last_ODR = 104.0f;

    G_isEnabled = 0;

    return LSM6DSL_STATUS_OK;
}

/**
 * @brief  Disable the sensor and relative resources
 * @retval 0 in case of success, an error code otherwise
 */
LSM6DSLStatusTypeDef LSM6DSLSensor_end()
{
    /* Disable both acc and gyro */
    if (LSM6DSLSensor_Disable_X() != LSM6DSL_STATUS_OK)
    {
        return LSM6DSL_STATUS_ERROR;
    }

    if (LSM6DSLSensor_Disable_G() != LSM6DSL_STATUS_OK)
    {
        return LSM6DSL_STATUS_ERROR;
    }

    return LSM6DSL_STATUS_OK;
}

/**
 * @brief  Enable LSM6DSL Accelerator
 * @retval LSM6DSL_STATUS_OK in case of success, an error code otherwise
 */
LSM6DSLStatusTypeDef LSM6DSLSensor_Enable_X(void)
{
    /* Check if the component is already enabled */
    if (X_isEnabled == 1)
    {
        return LSM6DSL_STATUS_OK;
    }

    /* Output data rate selection. */
    if (Set_X_ODR_When_Enabled(X_Last_ODR) == LSM6DSL_STATUS_ERROR)
    {
        return LSM6DSL_STATUS_ERROR;
    }

    X_isEnabled = 1;

    return LSM6DSL_STATUS_OK;
}

/**
 * @brief  Enable LSM6DSL Gyroscope
 * @retval LSM6DSL_STATUS_OK in case of success, an error code otherwise
 */
LSM6DSLStatusTypeDef LSM6DSLSensor_Enable_G(void)
{
    /* Check if the component is already enabled */
    if (G_isEnabled == 1)
    {
        return LSM6DSL_STATUS_OK;
    }

    /* Output data rate selection. */
    if (Set_G_ODR_When_Enabled(G_Last_ODR) == LSM6DSL_STATUS_ERROR)
    {
        return LSM6DSL_STATUS_ERROR;
    }

    G_isEnabled = 1;

    return LSM6DSL_STATUS_OK;
}

/**
 * @brief  Disable LSM6DSL Accelerator
 * @retval LSM6DSL_STATUS_OK in case of success, an error code otherwise
 */
LSM6DSLStatusTypeDef LSM6DSLSensor_Disable_X(void)
{
    /* Check if the component is already disabled */
    if (X_isEnabled == 0)
    {
        return LSM6DSL_STATUS_OK;
    }

    /* Store actual output data rate. */
    if (LSM6DSLSensor_Get_X_ODR(&X_Last_ODR) == LSM6DSL_STATUS_ERROR)
    {
        return LSM6DSL_STATUS_ERROR;
    }

    /* Output data rate selection - power down. */
    if (LSM6DSL_ACC_GYRO_W_ODR_XL(NULL, LSM6DSL_ACC_GYRO_ODR_XL_POWER_DOWN) == MEMS_ERROR)
    {
        return LSM6DSL_STATUS_ERROR;
    }

    X_isEnabled = 0;

    return LSM6DSL_STATUS_OK;
}

/**
 * @brief  Disable LSM6DSL Gyroscope
 * @retval LSM6DSL_STATUS_OK in case of success, an error code otherwise
 */
LSM6DSLStatusTypeDef LSM6DSLSensor_Disable_G(void)
{
    /* Check if the component is already disabled */
    if (G_isEnabled == 0)
    {
        return LSM6DSL_STATUS_OK;
    }

    /* Store actual output data rate. */
    if (LSM6DSLSensor_Get_G_ODR(&G_Last_ODR) == LSM6DSL_STATUS_ERROR)
    {
        return LSM6DSL_STATUS_ERROR;
    }

    /* Output data rate selection - power down */
    if (LSM6DSL_ACC_GYRO_W_ODR_G(NULL, LSM6DSL_ACC_GYRO_ODR_G_POWER_DOWN) == MEMS_ERROR)
    {
        return LSM6DSL_STATUS_ERROR;
    }

    G_isEnabled = 0;

    return LSM6DSL_STATUS_OK;
}

/**
 * @brief  Read ID of LSM6DSL Accelerometer and Gyroscope
 * @param  p_id the pointer where the ID of the device is stored
 * @retval LSM6DSL_STATUS_OK in case of success, an error code otherwise
 */
LSM6DSLStatusTypeDef LSM6DSLSensor_ReadID(uint8_t *p_id)
{
    if (!p_id)
    {
        return LSM6DSL_STATUS_ERROR;
    }

    /* Read WHO AM I register */
    if (LSM6DSL_ACC_GYRO_R_WHO_AM_I(NULL, p_id) == MEMS_ERROR)
    {
        return LSM6DSL_STATUS_ERROR;
    }

    return LSM6DSL_STATUS_OK;
}
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

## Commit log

2021-10-07 update read sensor
    update read sensor Acc
2021-10-14 update IMU detection hit action
    update IMU detection hit action
    [Block Diagram.SchDoc, CreationByte_DevBoard_v1 PCB.PcbDoc, CreationByte_DevBoard_v1.PrjPcb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]
2021-10-14 fix: vibration action run 300ms when hit detected
    fix: vibration action run 300ms when hit detected
    [Common.h, plan_task.c]
2021-10-14 fix: init current vibration level
    fix: init current vibration level
    [main.c, plan_task.c]
2021-11-20 Update buttons check and mqtt send message
    Update buttons check and mqtt send message
2021-11-27 fix bug user button
    fix bug user button
    [plan_task.c]
2021-11-28 fix bug button reverse check
    fix bug button reverse check
    [plan_task.c]
2021-11-29 change time check reverse button status and hold button
    change time check reverse button status and hold button
    [plan_task.c]
2021-12-04 change time detect reverse buttons
    [plan_task.c]
2021-12-04 change time detect reverse buttons
    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
    [plan_task.c]
2021-12-05 fw check buttons status
2021-12-09 update fix bug the user button
    update fix bug the user button
    [plan_task.c]
